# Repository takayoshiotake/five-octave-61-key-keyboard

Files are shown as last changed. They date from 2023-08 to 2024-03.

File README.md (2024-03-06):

# Five Octave

[][cc-by-sa]

A 61-key (5-octave) keyboard. Powered by [Vial](https://get.vial.today/) firmware.

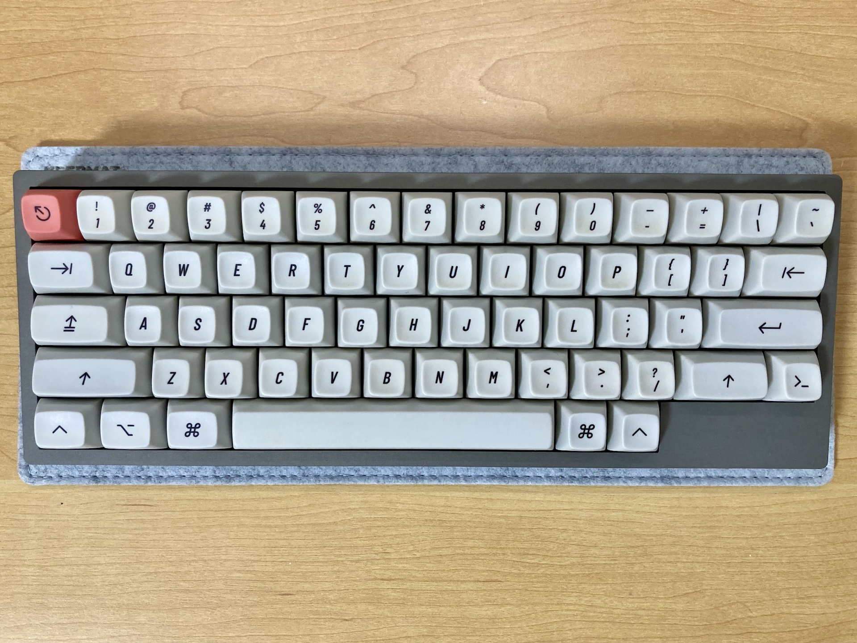
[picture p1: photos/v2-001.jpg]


## Layout

**Layer 0**:

📄 [keyboard-layout.png](layout/keyboard-layout.png) (v0.3.0)

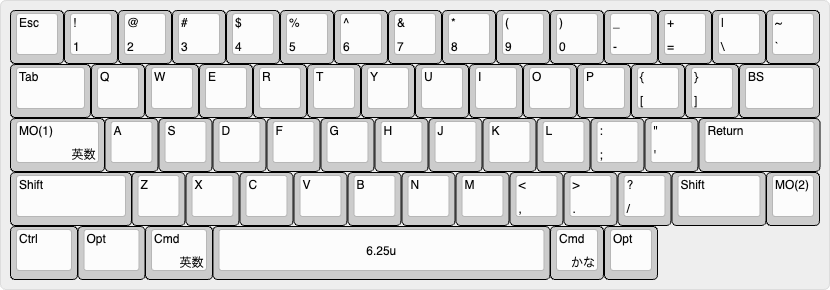
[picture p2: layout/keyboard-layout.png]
keyboard layout


MEMO: When pressed individually and released, it becomes the lower right keys (英数 and かな).

**Layer 1**:

📄 [keyboard-layout-1.png](layout/keyboard-layout-1.png)

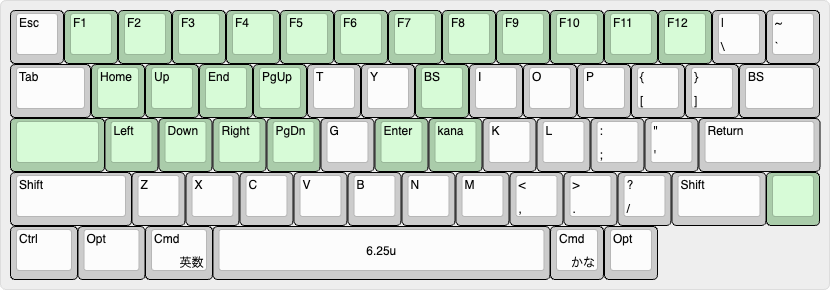
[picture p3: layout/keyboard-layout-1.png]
keyboard layout 1


**Layer 2**:

📄 [keyboard-layout-2.png](layout/keyboard-layout-2.png)

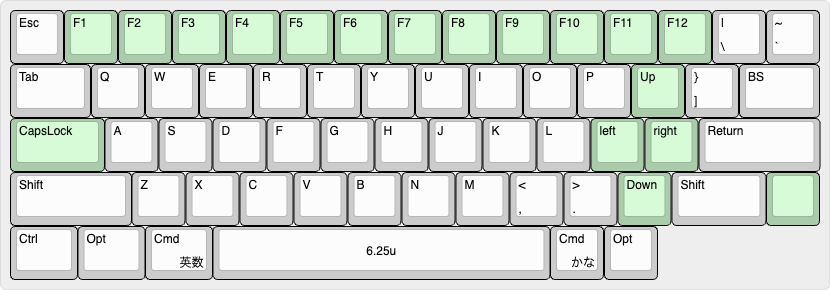
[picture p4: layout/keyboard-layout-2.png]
keyboard layout 2


MEMO: I couldn't figure out how to achieve 'fn' with adafruit_hid, so I'm using Karabiner to remap right_option to 'fn' and using it that way.

**RAW data for Keyboard Layout Editor v0.15:**

📄 [keyboard-layout.rawdata.json](layout/keyboard-layout.rawdata.json)

```json
[{"a":4,"f":3},"Esc","!\n1","@\n2","#\n3","$\n4","%\n5","^\n6","&\n7","*\n8","(\n9",")\n0","_\n-","+\n=","|\n\\","~\n`"],
[{"w":1.5},"Tab","Q","W","E","R","T","Y","U","I","O","P","{\n[","}\n]",{"w":1.5},"BS"],
[{"w":1.75},"MO(1)\n\n\n英数","A","S","D","F","G","H","J","K","L",":\n;","\"\n'",{"w":2.25},"Return"],
[{"w":2.25},"Shift","Z","X","C","V","B","N","M","<\n,",">\n.","?\n/",{"w":1.75},"Shift","MO(2)"],
[{"w":1.25},"Ctrl",{"w":1.25},"Opt",{"w":1.25},"Cmd\n\n\n英数",{"a":7,"w":6.25},"6.25u",{"a":4},"Cmd\n\n\nかな","Opt"]
```

📄 [keyboard-layout-1.rawdata.json](layout/keyboard-layout-1.rawdata.json)

```json
[{"a":4,"f":3},"Esc",{"c":"#aaccaa"},"F1","F2","F3","F4","F5","F6","F7","F8","F9","F10","F11","F12",{"c":"#cccccc"},"|\n\\","~\n`"],
[{"w":1.5},"Tab",{"c":"#aaccaa"},"Home","Up","End","PgUp",{"c":"#cccccc"},"T","Y","BS",{"c":"#cccccc"},"I","O","P","{\n[","}\n]",{"w":1.5},"BS"],
[{"c":"#aaccaa","w":1.75},"","Left","Down","Right","PgDn",{"c":"#cccccc"},"G",{"c":"#aaccaa"},"Enter","kana",{"c":"#cccccc"},"K","L",":\n;","\"\n'",{"w":2.25},"Return"],
[{"w":2.25},"Shift","Z","X","C","V","B","N","M","<\n,",">\n.","?\n/",{"w":1.75},"Shift",{"c":"#aaccaa"},"",{"c":"#cccccc"}],
[{"w":1.25},"Ctrl",{"w":1.25},"Opt",{"w":1.25},"Cmd\n\n\n英数",{"a":7,"w":6.25},"6.25u",{"a":4},"Cmd\n\n\nかな","Opt"]
```

📄 [keyboard-layout-2.rawdata.json](layout/keyboard-layout-2.rawdata.json)

```json
[{"a":4,"f":3},"Esc",{"c":"#aaccaa"},"F1","F2","F3","F4","F5","F6","F7","F8","F9","F10","F11","F12",{"c":"#cccccc"},"|\n\\","~\n`"],
[{"w":1.5},"Tab","Q","W","E","R","T","Y","U","I","O","P",{"c":"#aaccaa"},"Up",{"c":"#cccccc"},"}\n]",{"w":1.5},"BS"],
[{"c":"#aaccaa","w":1.75},"CapsLock",{"c":"#cccccc"},"A","S","D","F","G","H","J","K","L",{"c":"#aaccaa"},"left","right",{"c":"#cccccc","w":2.25},"Return"],
[{"w":2.25},"Shift","Z","X","C","V","B","N","M","<\n,",">\n.",{"c":"#aaccaa"},"Down",{"c":"#cccccc","w":1.75},"Shift",{"c":"#aaccaa"},"",{"c":"#cccccc"}],
[{"w":1.25},"Ctrl",{"w":1.25},"Opt",{"w":1.25},"Cmd\n\n\n英数",{"a":7,"w":6.25},"6.25u",{"a":4},"Cmd\n\n\nかな","Opt"]]
```

- 🔗 [Keyboard Layout Editor](http://www.keyboard-layout-editor.com/)

## BOM

| Material | QTY | Note |
|-|-:|-|
| Five Octave MCU Board | 1 | |
| Five Octave Keys Board | 1 | |
| Five Octave Enclosure | 1 | |
| 0151660169 | 1 | Molex 0.50mm pitch FFC, Type A, 127.00mm, 16 circuits |

- 🔗 [Molex Connector Part Number - 15166-0169 | Molex](https://www.molex.com/en-us/products/part-detail/151660169)

### Five Octave MCU Board

| Material | Symbol | QTY | Note | JLCPCB Part # |
|-|-|-:|-|-|
| 30pF 0402 | C1, C2 | 2 | | [C1570](https://jlcpcb.com/partdetail/1922-0402CG300J500NT/C1570) |
| 1uF 0402 | C3, C4 | 2 | | [C52923](https://jlcpcb.com/partdetail/53938-CL05A105KA5NQNC/C52923) |
| 100nF 0402 | C5-C14 | 10 | | [C307331](https://jlcpcb.com/partdetail/291005-CL05B104KB54PNC/C307331) |
| 10uF 0402 | C15, C16 | 2 | | [C15525](https://jlcpcb.com/partdetail/16204-CL05A106MQ5NUNC/C15525) |
| HRO_TYPE-C-31-M-12 | J1 | 1 | USB Type-C Connector, Korean Hroparts Elec | [C165948](https://jlcpcb.com/partdetail/Korean_HropartsElec-TYPE_C_31_M12/C165948) |
| AFC01-S16FCC-00 | J2 | 1 | FFC Connector 0.50mm pitch 16 circuits, JUSHUO | [C262272](https://jlcpcb.com/partdetail/Jushuo-AFC01_S16FCC00/C262272) |
| WS2812C-2020-V1 | LED1 | 1 | NeoPixel RGB LED 2x2mm, Worldsemi | [C2976072](https://jlcpcb.com/partdetail/Worldsemi-WS2812C_2020V1/C2976072) |
| 10KΩ 0402 | R1, R3 | 2 | | [C25744](https://jlcpcb.com/partdetail/26487-0402WGF1002TCE/C25744) |
| 1KΩ 0402 | R2, R4 | 2 | | [C11702](https://jlcpcb.com/partdetail/12256-0402WGF1001TCE/C11702) |
| 27Ω 0402 | R5, R6 | 2 | | [C352446](https://jlcpcb.com/partdetail/Resi-AECR0402F27R0K9/C352446) |
| 5.1KΩ 0402 | R7, R8 | 2 | | [C25905](https://jlcpcb.com/partdetail/26648-0402WGF5101TCE/C25905) |
| SKRPANE010 | SW1, SW2 | 2 | Tactile Switch, ALPS ALPINE | [C470426](https://jlcpcb.com/partdetail/Alpsalpine-SKRPANE010/C470426) |
| RP2040 | U1 | 1 | MCU, Raspberry Pi | [C2040](https://jlcpcb.com/partdetail/RaspberryPi-RP2040/C2040) |
| W25Q64JVXGIQ | U2 | 1 | 64M-bit Serial Flash, Winbond Electronics | [C2940195](https://jlcpcb.com/partdetail/WinbondElec-W25Q64JVXGIQ/C2940195) |
| AP2112K-3.3TRG1 | U3 | 1 | 3.3V Linear Voltage Regulators | [C51118](https://jlcpcb.com/partdetail/DiodesIncorporated-AP2112K_33TRG1/C51118) |
| X322512MSB4SI | Y1 | 1 | 12MHz 20pF Crystal Resonator, SMD-3225, Yangxing Tech | [C9002](https://jlcpcb.com/partdetail/YangxingTech-X322512MSB4SI/C9002) | 

### Five Octave Keys Board

| Material | Symbol | QTY | Note | JLCPCB Part # |
|-|-|-:|-|-|
| 1N4148WS | D1-D61 | 61 | | [C2128](https://jlcpcb.com/partdetail/2485-1N4148WS/C2128) |
| CPG151101S11-16 | SW1-SW61 | 61 | How Swap Socket, Kailh | [C5156480](https://jlcpcb.com/partdetail/Kailh-CPG151101S1116/C5156480) | 
| AFC01-S16FCC-00 | J1 | 1 | FFC Connector 0.50mm pitch 16 circuits, JUSHUO | [C262272](https://jlcpcb.com/partdetail/Jushuo-AFC01_S16FCC00/C262272) |

- 🔗 [JLCPCB | Assembly Parts Lib](https://jlcpcb.com/parts)

### Five Octave Enclosure

| Material | Symbol | QTY | Note |
|-|-|-:|-|
| Five Octave Enclosure - Case || 1 | (or Enclosure v2) |
| Five Octave Enclosure - Top Frame || 1 | (or Enclosure v2) |
| Screw M2 x 8mm || 4 | Secure Case and Top Frame |
| Screw M2 x 5mm or 4mm || 4 | Secure Case and Five Octave MCU |
| Poron 1.5t 3mm x 120mm || 2 | For gasket mounting |
| Poron 1.5t 3mm x 60mm || 6 | For gasket mounting |
| Poron 1.5t 3mm x 40mm || 2 | For gasket mounting |

## Schematic and PCB

### Five Octave MCU

📄 [Five_Octave_MCU.kicad_sch](electronics/Five_Octave_MCU/Five_Octave_MCU.kicad_sch) (v1.0.0)

📄 [Five_Octave_MCU.kicad_pcb](electronics/Five_Octave_MCU/Five_Octave_MCU.kicad_pcb) (v1.0.0)

📄 [Five_Octave_MCU.svg](electronics/Five_Octave_MCU/Five_Octave_MCU.svg)

schematic svg

### Five Octave Keys

📄 [Five_Octave_Keys.kicad_sch](electronics/Five_Octave_Keys/Five_Octave_Keys.kicad_sch) (v1.0.0)

📄 [Five_Octave_Keys.kicad_pcb](electronics/Five_Octave_Keys/Five_Octave_Keys.kicad_pcb) (v1.0.0)

📄 [Five_Octave_Keys.svg](electronics/Five_Octave_Keys/Five_Octave_Keys.svg)

schematic svg

#### Key-matrix (8x8)

| | C0 | C1 | C2  | C3  | C4 | C5 | C6 | C7 |
|----|---|---|-----|-----|---|---|---|---|
| R0 | Esc | | 1 | 2 | 3 | 4 | 5 | 6 |
| R1 | Tab | | | Q | W | E | R | T |
| R2 | Caps  | Z | X | A | S | D | F | G | 
| R3 | Shift | Ctrl | Opt | Cmd | Space | C | V | B |
| R4 | 7 | 8 | 9 | 0 | - | = | \ | ` |
| R5 | Y | U | I | O | P | [ | ] | BS |
| R6 | H | J | K | L | ; | ' | Return | Fn |
| R7 | N | M | , | . | / | Shift | Cmd | MO(1) | 

## Mechanics

### Five Octave Enclosure

📄 [Five_Octave_Enclosure.FCStd](mechanics/Five_Octave_Enclosure.FCStd) (v1.0.1)

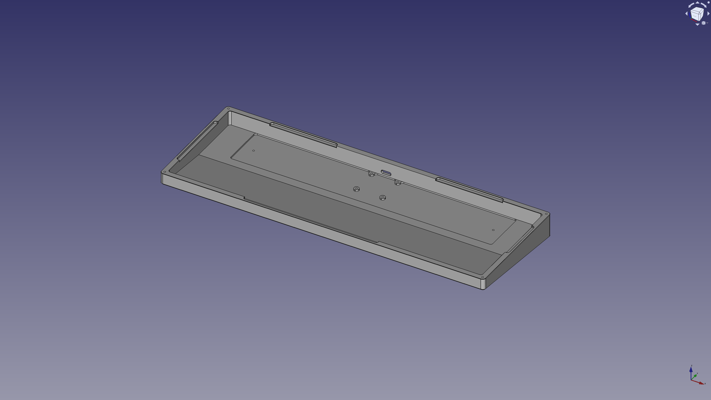
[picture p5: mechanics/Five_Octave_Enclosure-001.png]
enclosure png 001

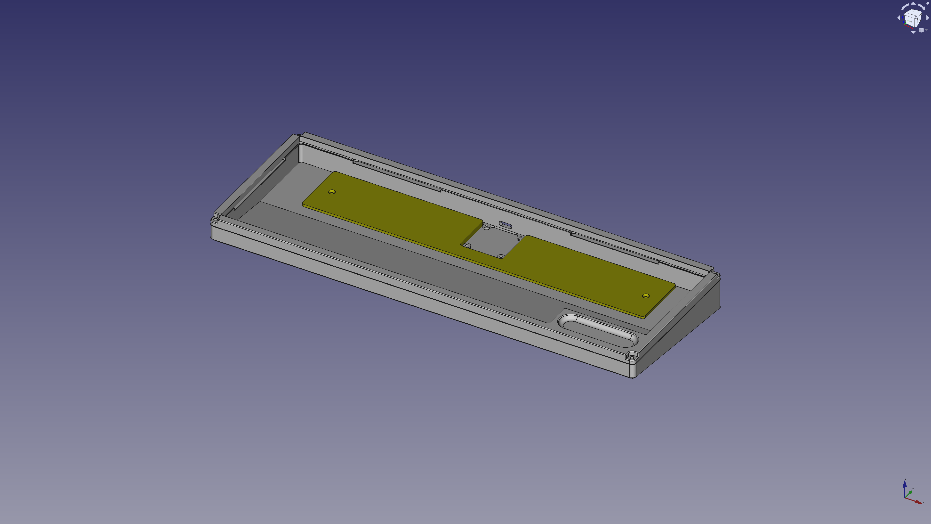
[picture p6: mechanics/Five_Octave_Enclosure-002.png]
enclosure png 002


### Five Octave Enclosure v2

📄 [Five_Octave_Enclosure_v2.FCStd](mechanics/Five_Octave_Enclosure_v2.FCStd) (v2.1.2)

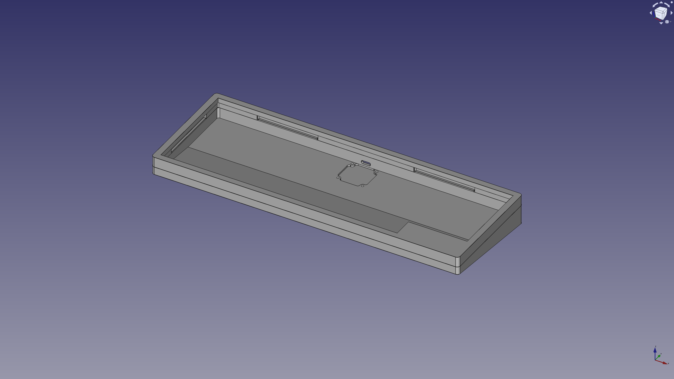
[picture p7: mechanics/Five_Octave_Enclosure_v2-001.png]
enclosure v2 png 001

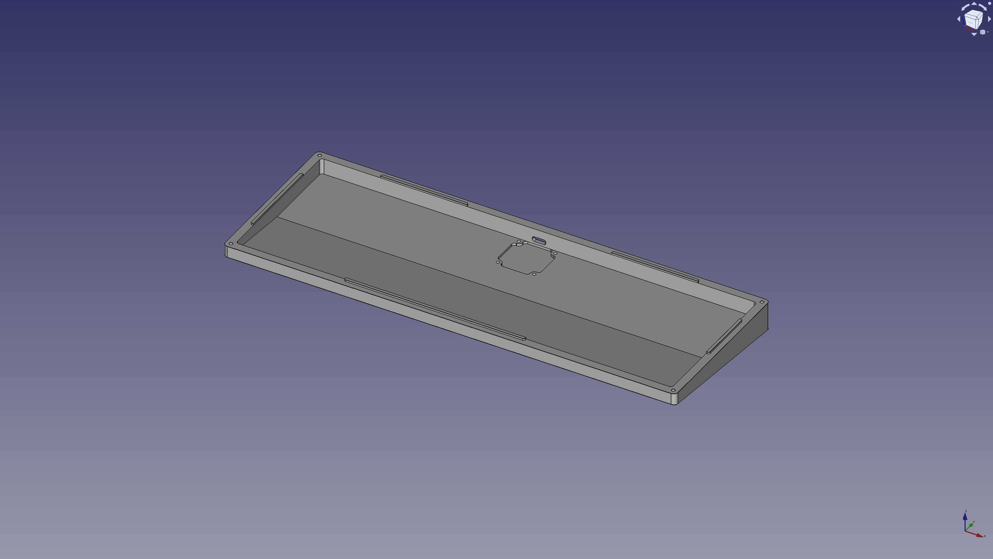
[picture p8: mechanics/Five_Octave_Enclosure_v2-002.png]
enclosure v2 png 002


### Plate

📄 [Five_Octave_Plate.kicad_pcb](electronics/Five_Octave_Plate/Five_Octave_Plate.kicad_pcb) (v1.0.0)

## Firmware

You can use Vial or CircuitPython.

### Vial

- Built UF2
    - 📄 [takayoshiotake_five_octave_vial_20240103.uf2](vial-bin/takayoshiotake_five_octave_vial_20240103.uf2)
- Code
    -  🔗 <https://github.com/vial-kb/vial-qmk/tree/vial/keyboards/takayoshiotake/five_octave>
    -  🔗 <https://github.com/vial-kb/vial-qmk/tree/49f5eec0d46f3524850885ffae9dee2982312e50>

See [vial-porting](vial-porting) for more details.

### CircuitPython

Software for the Five Octave runs on CircuitPython.
Its CircuitPython is the same as the one for Octave (<https://github.com/takayoshiotake/octave-12-key-macropad>).

- Built UF2
    - 🔗 <https://adafruit-circuit-python.s3.amazonaws.com/index.html?prefix=bin/takayoshiotake_octave_rp2040/>
    - 📄 [adafruit-circuitpython-takayoshiotake_octave_rp2040-en_US-8.2.6.uf2](circuitpython-bin/adafruit-circuitpython-takayoshiotake_octave_rp2040-en_US-8.2.6.uf2)
- Code
    - 🔗 [adafruit/circuitpython](https://github.com/adafruit/circuitpython)
        - 🔗 <https://github.com/adafruit/circuitpython/tree/main/ports/raspberrypi/boards/takayoshiotake_octave_rp2040>

See [circuitpython-app/README.md](software/README.md) for application software.

## Gallery

Keycap: Drop + biip MT3 Extended 2048

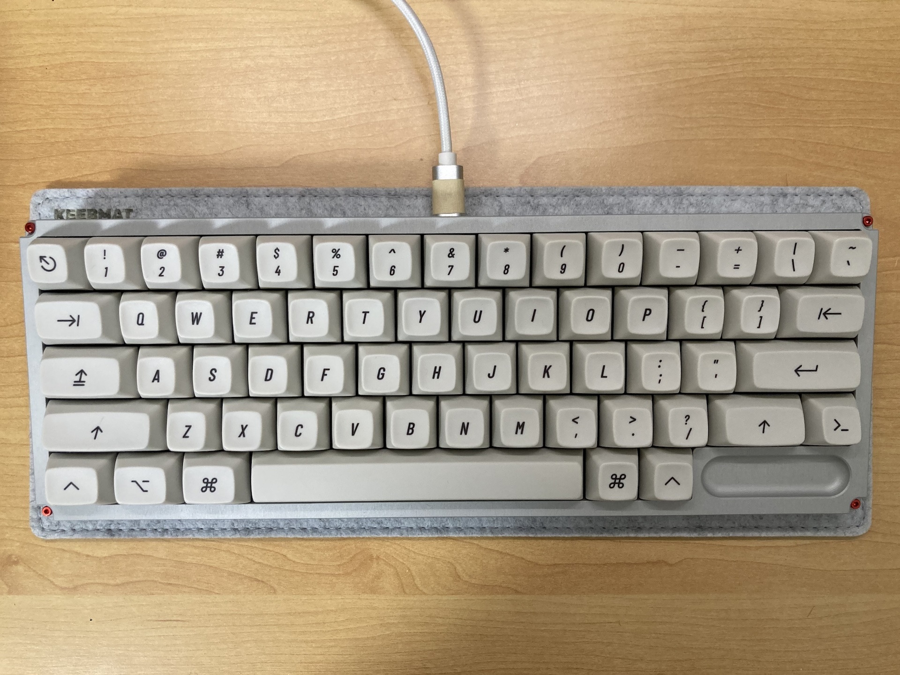
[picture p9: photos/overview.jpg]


MEMO: Alminum 6061 CNC + Bead blasting 120 mesh + Anodizing natural matte by JLCPCB (Five Octave Enclosure v1.0.0)

### Photos with Enclosure v2

Keycap: Drop + biip MT3 Extended 2048


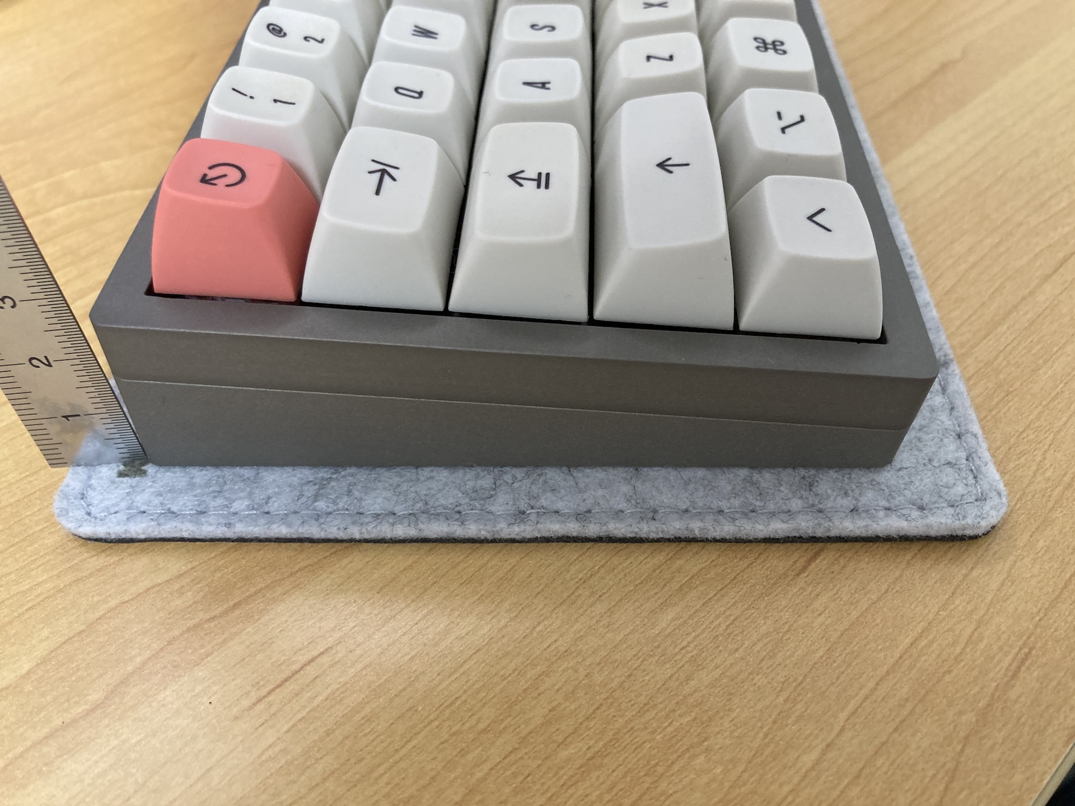
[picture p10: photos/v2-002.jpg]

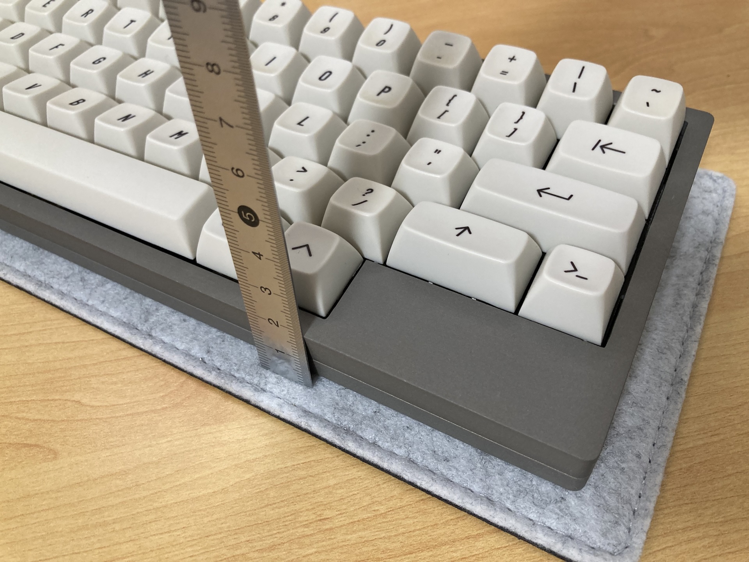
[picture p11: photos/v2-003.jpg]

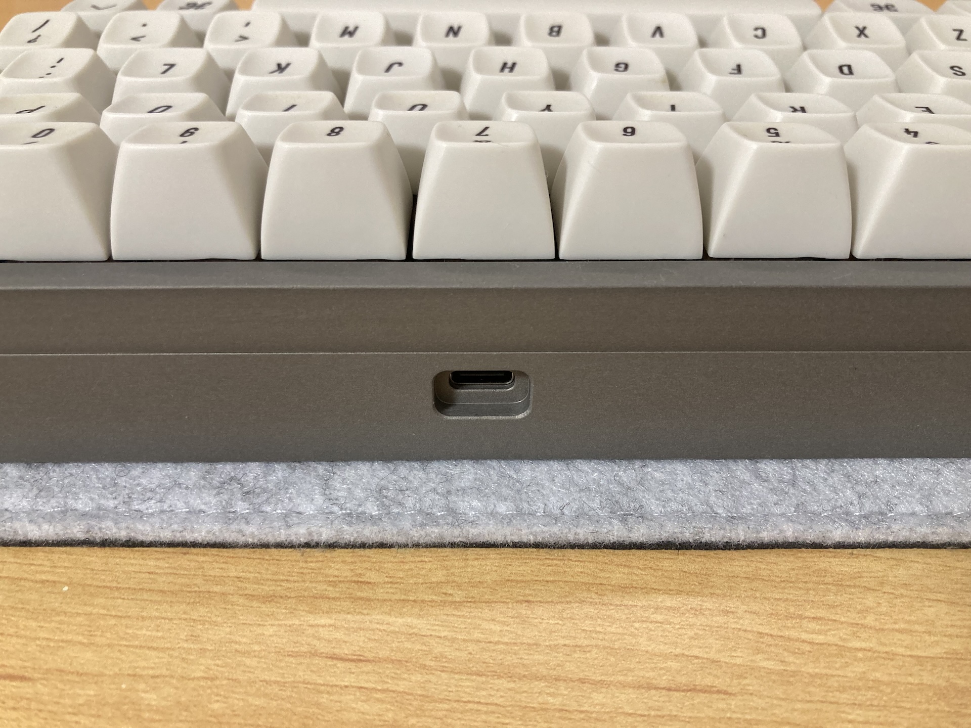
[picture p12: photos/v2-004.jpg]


MEMO: Alminum 6061 CNC + Bead blasting 150 mesh + Hardcoat anodizing natural matte by JLCPCB (Five Octave Enclosure v2.1.1)

## License

This work is licensed under a
[Creative Commons Attribution-ShareAlike 4.0 International License][cc-by-sa].

[][cc-by-sa]

[cc-by-sa]: http://creativecommons.org/licenses/by-sa/4.0/
[cc-by-sa-image]: https://licensebuttons.net/l/by-sa/4.0/88x31.png
[cc-by-sa-shield]: https://img.shields.io/badge/license-CC%20BY--SA%204.0-lightgrey.svg

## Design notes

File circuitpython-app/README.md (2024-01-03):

# CircuitPython app

## Setup

1. Install CircuitPython 8.x.x
    1. Connect Octave via USB
    2. Reboot Octave by holding down BOOT and pressing RESET
    3. Copy (drag & drop) uf2 to RPI-RP2
        - 📄 [adafruit-circuitpython-takayoshiotake_octave_rp2040-en_US-8.2.6.uf2](../circuitpython-bin/adafruit-circuitpython-takayoshiotake_octave_rp2040-en_US-8.2.6.uf2)
        - 🔗 <https://circuitpython.org/board/takayoshiotake_octave_rp2040/>

2. Renaming CIRCUITPY to OCTAVE_CP

    - 🔗 <https://learn.adafruit.com/welcome-to-circuitpython/renaming-circuitpy>

## Install packages

```shell-session
% poetry install
% poetry shell
(.venv) % circup --path /Volumes/OCTAVE_CP install -r requirements.txt
```

Alternatively:

```shell-session
% cp -r lib /Volumes/OCTAVE_CP/
```

## Upload

```shell-session
% cp boot.py code.py /Volumes/OCTAVE_CP/
% cp -r octave_pcb /Volumes/OCTAVE_CP/
```

MEMO: After uploading boot.py, you will need to hold down SW1 during boot to mount it as a USB drive.

## Note

🔗 <https://learn.adafruit.com/circuitpython-essentials/circuitpython-resetting>

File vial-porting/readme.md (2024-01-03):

# Five Octave

Five Octave

Vial firmware for the Five Octave 60% keyboard. You can find other information including hardware design in the [GitHub repository](https://github.com/takayoshiotake/five-octave-61-key-keyboard).

Keyboard Maintainer: [takayoshiotake](https://github.com/takayoshiotake)

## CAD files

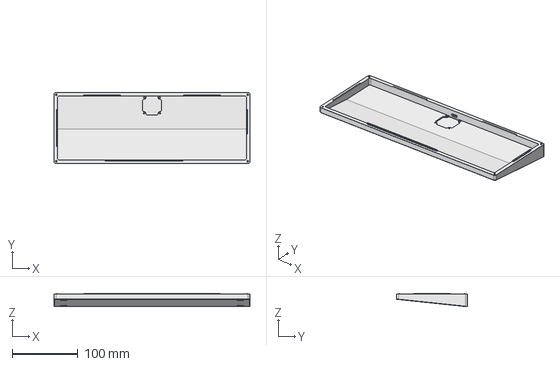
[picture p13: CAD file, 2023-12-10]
mechanics/Five_Octave_Enclosure_v2.FCStd
298.9 x 108.4 x 20.5 mm

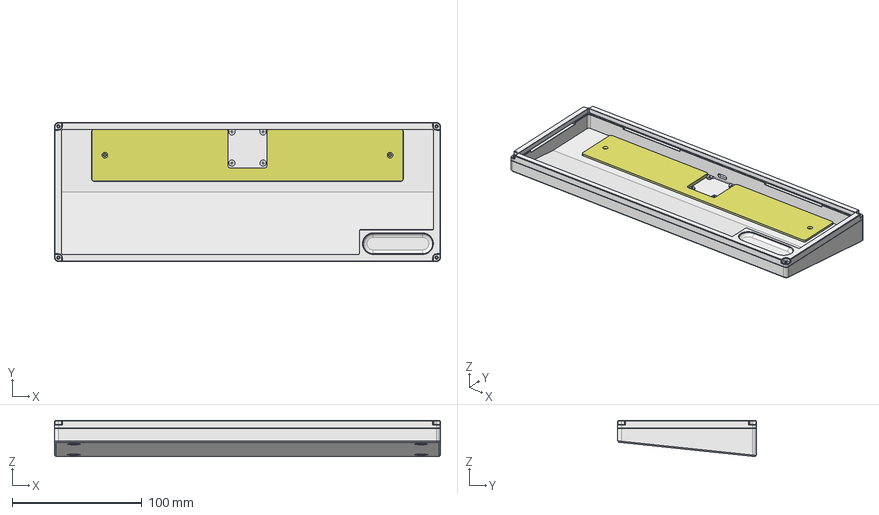
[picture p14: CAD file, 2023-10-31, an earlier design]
mechanics/Five_Octave_Enclosure.FCStd
297.8 x 107.3 x 27.9 mm
Case
Top Frame
Weight

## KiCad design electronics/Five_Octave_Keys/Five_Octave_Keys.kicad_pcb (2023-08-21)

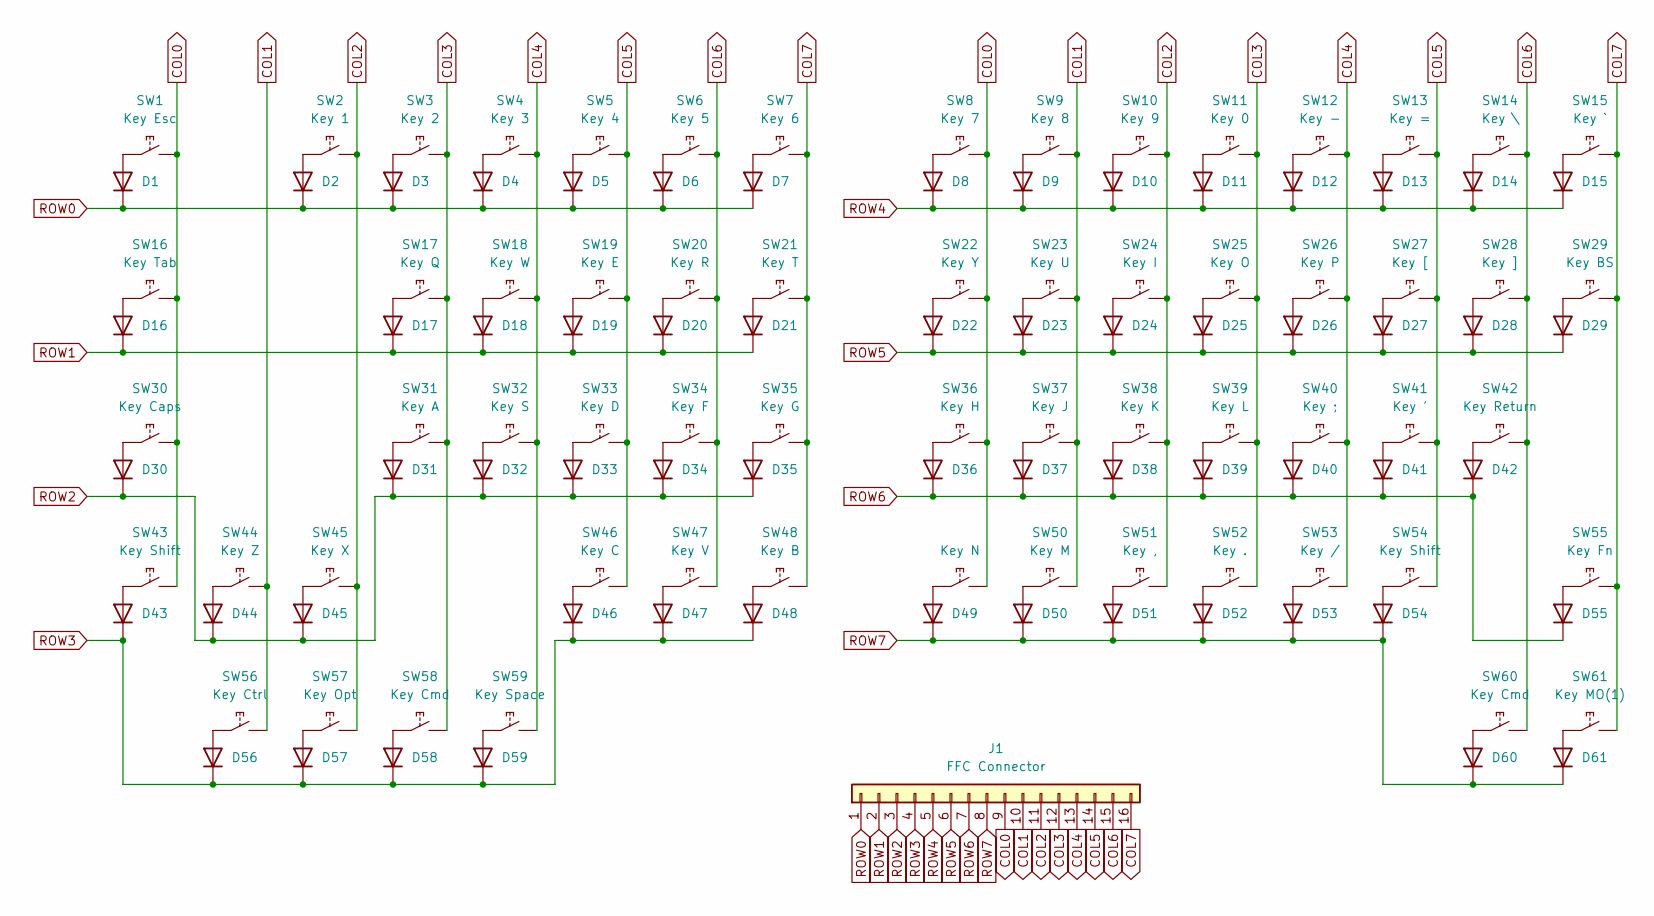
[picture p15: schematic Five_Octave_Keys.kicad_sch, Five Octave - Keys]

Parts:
D1, D2, D3, D4, D5, D6, D7, D8, D9, D10, D11, D12, D13, D14, D15, D16, D17, D18, D19, D20, D21, D22, D23, D24, D25, D26, D27, D28, D29, D30, D31, D32, D33, D34, D35, D36, D37, D38, D39, D40, D41, D42, D43, D44, D45, D46, D47, D48, D49, D50, D51, D52, D53, D54, D55, D56, D57, D58, D59, D60, D61: 1N4148WS; D_SOD-323F; LCSC C2128
J1: FFC Connector; JUSHUO_AFC01-S16FCC-00; LCSC C262272
SW1: Key Esc; Hot_Swap_Socket_CPG151101S11; LCSC C5156480
SW2: Key 1; Hot_Swap_Socket_CPG151101S11; LCSC C5156480
SW3: Key 2; Hot_Swap_Socket_CPG151101S11; LCSC C5156480
SW4: Key 3; Hot_Swap_Socket_CPG151101S11; LCSC C5156480
SW5: Key 4; Hot_Swap_Socket_CPG151101S11; LCSC C5156480
SW6: Key 5; Hot_Swap_Socket_CPG151101S11; LCSC C5156480
SW7: Key 6; Hot_Swap_Socket_CPG151101S11; LCSC C5156480
SW8: Key 7; Hot_Swap_Socket_CPG151101S11; LCSC C5156480
SW9: Key 8; Hot_Swap_Socket_CPG151101S11; LCSC C5156480
SW10: Key 9; Hot_Swap_Socket_CPG151101S11; LCSC C5156480
SW11: Key 0; Hot_Swap_Socket_CPG151101S11; LCSC C5156480
SW12: Key -; Hot_Swap_Socket_CPG151101S11; LCSC C5156480
SW13: Key =; Hot_Swap_Socket_CPG151101S11; LCSC C5156480
SW14: Key \; Hot_Swap_Socket_CPG151101S11; LCSC C5156480
SW15: Key `; Hot_Swap_Socket_CPG151101S11; LCSC C5156480
SW16: Key Tab; Hot_Swap_Socket_CPG151101S11; LCSC C5156480
SW17: Key Q; Hot_Swap_Socket_CPG151101S11; LCSC C5156480
SW18: Key W; Hot_Swap_Socket_CPG151101S11; LCSC C5156480
SW19: Key E; Hot_Swap_Socket_CPG151101S11; LCSC C5156480
SW20: Key R; Hot_Swap_Socket_CPG151101S11; LCSC C5156480
SW21: Key T; Hot_Swap_Socket_CPG151101S11; LCSC C5156480
SW22: Key Y; Hot_Swap_Socket_CPG151101S11; LCSC C5156480
SW23: Key U; Hot_Swap_Socket_CPG151101S11; LCSC C5156480
SW24: Key I; Hot_Swap_Socket_CPG151101S11; LCSC C5156480
SW25: Key O; Hot_Swap_Socket_CPG151101S11; LCSC C5156480
SW26: Key P; Hot_Swap_Socket_CPG151101S11; LCSC C5156480
SW27: Key [; Hot_Swap_Socket_CPG151101S11; LCSC C5156480
SW28: Key ]; Hot_Swap_Socket_CPG151101S11; LCSC C5156480
SW29: Key BS; Hot_Swap_Socket_CPG151101S11; LCSC C5156480
SW30: Key Caps; Hot_Swap_Socket_CPG151101S11; LCSC C5156480
SW31: Key A; Hot_Swap_Socket_CPG151101S11; LCSC C5156480
SW32: Key S; Hot_Swap_Socket_CPG151101S11; LCSC C5156480
SW33: Key D; Hot_Swap_Socket_CPG151101S11; LCSC C5156480
SW34: Key F; Hot_Swap_Socket_CPG151101S11; LCSC C5156480
SW35: Key G; Hot_Swap_Socket_CPG151101S11; LCSC C5156480
SW36: Key H; Hot_Swap_Socket_CPG151101S11; LCSC C5156480
SW37: Key J; Hot_Swap_Socket_CPG151101S11; LCSC C5156480
SW38: Key K; Hot_Swap_Socket_CPG151101S11; LCSC C5156480
SW39: Key L; Hot_Swap_Socket_CPG151101S11; LCSC C5156480
SW40: Key ;; Hot_Swap_Socket_CPG151101S11; LCSC C5156480
SW41: Key '; Hot_Swap_Socket_CPG151101S11; LCSC C5156480
SW42: Key Return; Hot_Swap_Socket_CPG151101S11; LCSC C5156480
SW43, SW54: Key Shift; Hot_Swap_Socket_CPG151101S11; LCSC C5156480
SW44: Key Z; Hot_Swap_Socket_CPG151101S11; LCSC C5156480
SW45: Key X; Hot_Swap_Socket_CPG151101S11; LCSC C5156480
SW46: Key C; Hot_Swap_Socket_CPG151101S11; LCSC C5156480
SW47: Key V; Hot_Swap_Socket_CPG151101S11; LCSC C5156480
SW48: Key B; Hot_Swap_Socket_CPG151101S11; LCSC C5156480
SW49: Key N; Hot_Swap_Socket_CPG151101S11; LCSC C5156480
SW50: Key M; Hot_Swap_Socket_CPG151101S11; LCSC C5156480
SW51: Key ,; Hot_Swap_Socket_CPG151101S11; LCSC C5156480
SW52: Key .; Hot_Swap_Socket_CPG151101S11; LCSC C5156480
SW53: Key /; Hot_Swap_Socket_CPG151101S11; LCSC C5156480
SW55: Key Fn; Hot_Swap_Socket_CPG151101S11; LCSC C5156480
SW56: Key Ctrl; Hot_Swap_Socket_CPG151101S11; LCSC C5156480
SW57: Key Opt; Hot_Swap_Socket_CPG151101S11; LCSC C5156480
SW58, SW60: Key Cmd; Hot_Swap_Socket_CPG151101S11; LCSC C5156480
SW59: Key Space; Hot_Swap_Socket_CPG151101S11; LCSC C5156480
SW61: Key MO(1); Hot_Swap_Socket_CPG151101S11; LCSC C5156480

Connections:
COL0: J1.9, SW1.2, SW8.2, SW16.2, SW22.2, SW30.2, SW36.2, SW43.2, SW49.2
COL1: J1.10, SW9.2, SW23.2, SW37.2, SW44.2, SW50.2, SW56.2
COL2: J1.11, SW2.2, SW10.2, SW24.2, SW38.2, SW45.2, SW51.2, SW57.2
COL3: J1.12, SW3.2, SW11.2, SW17.2, SW25.2, SW31.2, SW39.2, SW52.2, SW58.2
COL4: J1.13, SW4.2, SW12.2, SW18.2, SW26.2, SW32.2, SW40.2, SW53.2, SW59.2
COL5: J1.14, SW5.2, SW13.2, SW19.2, SW27.2, SW33.2, SW41.2, SW46.2, SW54.2
COL6: J1.15, SW6.2, SW14.2, SW20.2, SW28.2, SW34.2, SW42.2, SW47.2, SW60.2
COL7: J1.16, SW7.2, SW15.2, SW21.2, SW29.2, SW35.2, SW48.2, SW55.2, SW61.2
unnamed: D1.2 (A), SW1.1
unnamed: D2.2 (A), SW2.1
unnamed: D3.2 (A), SW3.1
unnamed: D4.2 (A), SW4.1
unnamed: D5.2 (A), SW5.1
unnamed: D6.2 (A), SW6.1
unnamed: D7.2 (A), SW7.1
unnamed: D8.2 (A), SW8.1
unnamed: D9.2 (A), SW9.1
unnamed: D10.2 (A), SW10.1
unnamed: D11.2 (A), SW11.1
unnamed: D12.2 (A), SW12.1
unnamed: D13.2 (A), SW13.1
unnamed: D14.2 (A), SW14.1
unnamed: D15.2 (A), SW15.1
unnamed: D16.2 (A), SW16.1
unnamed: D17.2 (A), SW17.1
unnamed: D18.2 (A), SW18.1
unnamed: D19.2 (A), SW19.1
unnamed: D20.2 (A), SW20.1
unnamed: D21.2 (A), SW21.1
unnamed: D22.2 (A), SW22.1
unnamed: D23.2 (A), SW23.1
unnamed: D24.2 (A), SW24.1
unnamed: D25.2 (A), SW25.1
unnamed: D26.2 (A), SW26.1
unnamed: D27.2 (A), SW27.1
unnamed: D28.2 (A), SW28.1
unnamed: D29.2 (A), SW29.1
unnamed: D30.2 (A), SW30.1
unnamed: D31.2 (A), SW31.1
unnamed: D32.2 (A), SW32.1
unnamed: D33.2 (A), SW33.1
unnamed: D34.2 (A), SW34.1
unnamed: D35.2 (A), SW35.1
unnamed: D36.2 (A), SW36.1
unnamed: D37.2 (A), SW37.1
unnamed: D38.2 (A), SW38.1
unnamed: D39.2 (A), SW39.1
unnamed: D40.2 (A), SW40.1
unnamed: D41.2 (A), SW41.1
unnamed: D42.2 (A), SW42.1
unnamed: D43.2 (A), SW43.1
unnamed: D44.2 (A), SW44.1
unnamed: D45.2 (A), SW45.1
unnamed: D46.2 (A), SW46.1
unnamed: D47.2 (A), SW47.1
unnamed: D48.2 (A), SW48.1
unnamed: D49.2 (A), SW49.1
unnamed: D50.2 (A), SW50.1
unnamed: D51.2 (A), SW51.1
unnamed: D52.2 (A), SW52.1
unnamed: D53.2 (A), SW53.1
unnamed: D54.2 (A), SW54.1
unnamed: D55.2 (A), SW55.1
unnamed: D56.2 (A), SW56.1
unnamed: D57.2 (A), SW57.1
unnamed: D58.2 (A), SW58.1
unnamed: D59.2 (A), SW59.1
unnamed: D60.2 (A), SW60.1
unnamed: D61.2 (A), SW61.1
ROW0: D1.1 (K), D2.1 (K), D3.1 (K), D4.1 (K), D5.1 (K), D6.1 (K), D7.1 (K), J1.1
ROW1: D16.1 (K), D17.1 (K), D18.1 (K), D19.1 (K), D20.1 (K), D21.1 (K), J1.2
ROW2: D30.1 (K), D31.1 (K), D32.1 (K), D33.1 (K), D34.1 (K), D35.1 (K), D44.1 (K), D45.1 (K), J1.3
ROW3: D43.1 (K), D46.1 (K), D47.1 (K), D48.1 (K), D56.1 (K), D57.1 (K), D58.1 (K), D59.1 (K), J1.4
ROW4: D8.1 (K), D9.1 (K), D10.1 (K), D11.1 (K), D12.1 (K), D13.1 (K), D14.1 (K), D15.1 (K), J1.5
ROW5: D22.1 (K), D23.1 (K), D24.1 (K), D25.1 (K), D26.1 (K), D27.1 (K), D28.1 (K), D29.1 (K), J1.6
ROW6: D36.1 (K), D37.1 (K), D38.1 (K), D39.1 (K), D40.1 (K), D41.1 (K), D42.1 (K), D55.1 (K), J1.7
ROW7: D49.1 (K), D50.1 (K), D51.1 (K), D52.1 (K), D53.1 (K), D54.1 (K), D60.1 (K), D61.1 (K), J1.8

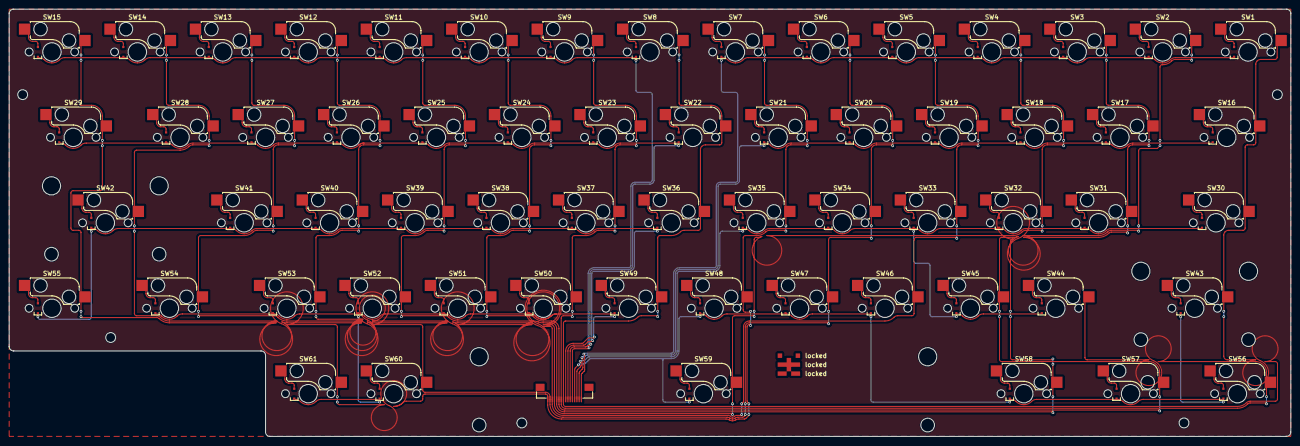
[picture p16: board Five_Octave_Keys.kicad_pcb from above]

Board: 2 copper layers, 285.8 x 95.2 mm, 123 parts (0 on the bottom side), 77 nets.

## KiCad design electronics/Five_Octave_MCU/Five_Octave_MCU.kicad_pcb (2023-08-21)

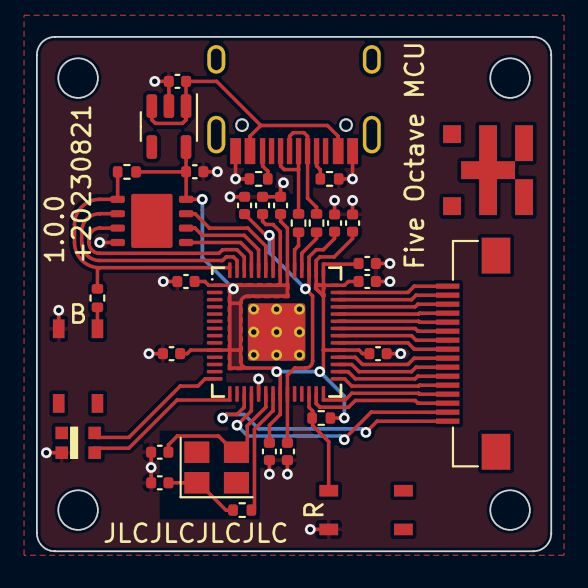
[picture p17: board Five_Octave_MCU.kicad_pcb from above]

Board: 2 copper layers, 28.6 x 28.6 mm, 33 parts (0 on the bottom side), 39 nets.

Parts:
C1, C2: 30pF; C_0402_1005Metric
C3, C4: 1uF; C_0402_1005Metric
C5, C6, C7, C8, C9, C10, C11, C12, C13, C14: 0.1uF; C_0402_1005Metric
C15, C16: 10uF; C_0402_1005Metric
J1: HRO_TYPE-C-31-M-12
J2: FFC Connector; JUSHUO_AFC01-S16FCC-00
LED1: WS2812C-2020-V1; WS2812C-2020
R1, R3: 10K; R_0402_1005Metric
R2, R4: 1K; R_0402_1005Metric
R5, R6: 27; R_0402_1005Metric
R7, R8: 5.1K; R_0402_1005Metric
SW1, SW2: Alps_Alpine_SKRP; Tactile_Switch_SKRP_Series
U1: Raspberry_Pi_RP2040; RP2040_QFN-56
U2: W25Q64JVXGIQ; XSON-8-EP_4x4mm
U3: AP2112K-3.3; SOT-23-5
Y1: 12MHz; Crystal_SMD_3225-4Pin_3.2x2.5mm

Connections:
+1V1: C4.1, C13.1, C14.1, U1.23 (DVDD), U1.45 (VREG_VOUT), U1.50 (DVDD)
+3V3: C3.1, C5.1, C6.1, C7.1, C8.1, C9.1, C10.1, C11.1, C12.1, C16.1, R1.1, R3.1, U1.1 (IOVDD), U1.10 (IOVDD), U1.22 (IOVDD), U1.33 (IOVDD), U1.42 (IOVDD), U1.43 (ADC_AVDD), U1.44 (VREG_VIN), U1.48 (USB_VDD), U1.49 (IOVDD), U2.8 (VCC), U3.5 (VOUT)
+5V: C15.1, J1.A4/B9 (VBUS), J1.A9/B4 (VBUS), U3.1 (VIN), U3.3 (EN)
COL0: J2.8, U1.32 (GPIO21)
COL1: J2.7, U1.31 (GPIO20)
COL2: J2.6, U1.30 (GPIO19)
COL3: J2.5, U1.29 (GPIO18)
COL4: J2.4, U1.28 (GPIO17)
COL5: J2.3, U1.27 (GPIO16)
COL6: J2.2, U1.18 (GPIO15)
COL7: J2.1, U1.17 (GPIO14)
D+: R5.1, U1.47 (USB_DP)
D-: R6.1, U1.46 (USB_DM)
GND: C1.2, C2.2, C3.2, C4.2, C5.2, C6.2, C7.2, C8.2, C9.2, C10.2, C11.2, C12.2, C13.2, C14.2, C15.2, C16.2, J1.A1/B12 (GND), J1.A12/B1 (GND), LED1.3 (VSS), R7.2, R8.2, SW1.3, SW2.3, U1.19 (TESTEN), U1.57 (GND), U2.4 (GND), U3.2 (GND)
NEOPIX: LED1.4 (DIN), U1.15 (GPIO12)
NEOPIX_POWER: LED1.1 (VDD), U1.14 (GPIO11)
unnamed: C2.1, R2.2, Y1.1
unnamed: J1.A5 (CC1), R8.1
unnamed: J1.B5 (CC2), R7.1
unnamed: J1.A6 (D+), J1.B6 (D+), R5.2
unnamed: J1.A7 (D-), J1.B7 (D-), R6.2
unnamed: R4.2, SW2.1
unnamed: U1.52 (QSPI_SCLK), U2.6 (CLK)
unnamed: U1.53 (QSPI_SD0), U2.5 (DI(IO0))
unnamed: U1.55 (QSPI_SD1), U2.2 (DO(IO1))
unnamed: U1.54 (QSPI_SD2), U2.3 (IO2)
unnamed: U1.51 (QSPI_SD3), U2.7 (IO3)
unnamed: R1.2, SW1.1, U1.26 (RUN)
unnamed: C1.1, U1.20 (XIN), Y1.3
unnamed: R2.1, U1.21 (XOUT)
QSPI_SS_N: R3.2, R4.1, U1.56 (QSPI_SS_N), U2.1 (~CS)
ROW0: J2.16, U1.41 (GPIO29/ADC3)
ROW1: J2.15, U1.40 (GPIO28/ADC2)
ROW2: J2.14, U1.39 (GPIO27/ADC1)
ROW3: J2.13, U1.38 (GPIO26/ADC0)
ROW4: J2.12, U1.37 (GPIO25)
ROW5: J2.11, U1.36 (GPIO24)
ROW6: J2.10, U1.35 (GPIO23)
ROW7: J2.9, U1.34 (GPIO22)

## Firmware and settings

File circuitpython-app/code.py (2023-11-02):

import collections
import time

import board
import digitalio
import usb_hid
from adafruit_hid.consumer_control import ConsumerControl
from adafruit_hid.consumer_control_code import ConsumerControlCode
from adafruit_hid.keyboard import Keyboard
from adafruit_hid.keyboard_layout_us import KeyboardLayoutUS
from adafruit_hid.keycode import Keycode
from adafruit_hid.mouse import Mouse

from octave_pcb.key_event import KeyEvent, KeyEventPlanner
from octave_pcb.key_matrix import KeyMatrix


class CodeType:
  KEYBOARD = 0
  MOUSE_MOVE = 1
  MOUSE_BUTTON = 2
  CONSUMER_CONTROL = 3


class KeycodeJp:
  JAPANESE_HENKAN = 0x8A  # International4
  JAPANESE_MUHENKAN = 0x8B  # International5
  JAPANESE_KANA = 0x90  # LANG1
  JAPANESE_EISUU = 0x91  # LANG2


class KeycodeLayer:
  MO1 = 0xFF01
  MO2 = 0xFF02


def is_code_mo(code):
  return True if code == KeycodeLayer.MO1 or code == KeycodeLayer.MO2 else False


ComplexModifierAssignment = collections.namedtuple('ComplexModifierAssignment', ['modifier', 'code_for_standalone'])
"""
1) If you release the key before it becomes a long press, send the standalone code.
2) When a key becomes a long press, or just before another KeyAssignment becomes press,
    the modifier becomes press.
"""

KeyAssignment = collections.namedtuple('KeyAssignment', ['type', 'code'])
LambdaAssignment = collections.namedtuple('LambdaAssignment', ['on_press', 'on_release'])


SCAN_KEY_MATRIX_INTERVAL = 0.02


KEY_MAP_LAYERS = [
    [
        # ROW0
        KeyAssignment(CodeType.KEYBOARD, Keycode.ESCAPE),
        None,
        KeyAssignment(CodeType.KEYBOARD, Keycode.ONE),
        KeyAssignment(CodeType.KEYBOARD, Keycode.TWO),
        KeyAssignment(CodeType.KEYBOARD, Keycode.THREE),
        KeyAssignment(CodeType.KEYBOARD, Keycode.FOUR),
        KeyAssignment(CodeType.KEYBOARD, Keycode.FIVE),
        KeyAssignment(CodeType.KEYBOARD, Keycode.SIX),
        # ROW1
        KeyAssignment(CodeType.KEYBOARD, Keycode.TAB),
        None,
        None,
        KeyAssignment(CodeType.KEYBOARD, Keycode.Q),
        KeyAssignment(CodeType.KEYBOARD, Keycode.W),
        KeyAssignment(CodeType.KEYBOARD, Keycode.E),
        KeyAssignment(CodeType.KEYBOARD, Keycode.R),
        KeyAssignment(CodeType.KEYBOARD, Keycode.T),
        # ROW2
        ComplexModifierAssignment(KeycodeLayer.MO1, KeycodeJp.JAPANESE_EISUU),  # CAPS_LOCK
        KeyAssignment(CodeType.KEYBOARD, Keycode.Z),
        KeyAssignment(CodeType.KEYBOARD, Keycode.X),
        KeyAssignment(CodeType.KEYBOARD, Keycode.A),
        KeyAssignment(CodeType.KEYBOARD, Keycode.S),
        KeyAssignment(CodeType.KEYBOARD, Keycode.D),
        KeyAssignment(CodeType.KEYBOARD, Keycode.F),
        KeyAssignment(CodeType.KEYBOARD, Keycode.G),
        # ROW3
        KeyAssignment(CodeType.KEYBOARD, Keycode.LEFT_SHIFT),
        KeyAssignment(CodeType.KEYBOARD, Keycode.LEFT_CONTROL),
        KeyAssignment(CodeType.KEYBOARD, Keycode.LEFT_ALT),  # left_option
        ComplexModifierAssignment(Keycode.LEFT_GUI, KeycodeJp.JAPANESE_EISUU),  # left_command
        KeyAssignment(CodeType.KEYBOARD, Keycode.SPACE),
        KeyAssignment(CodeType.KEYBOARD, Keycode.C),
        KeyAssignment(CodeType.KEYBOARD, Keycode.V),
        KeyAssignment(CodeType.KEYBOARD, Keycode.B),
        # ROW4
        KeyAssignment(CodeType.KEYBOARD, Keycode.SEVEN),
        KeyAssignment(CodeType.KEYBOARD, Keycode.EIGHT),
        KeyAssignment(CodeType.KEYBOARD, Keycode.NINE),
        KeyAssignment(CodeType.KEYBOARD, Keycode.ZERO),
        KeyAssignment(CodeType.KEYBOARD, Keycode.MINUS),
        KeyAssignment(CodeType.KEYBOARD, Keycode.EQUALS),
        KeyAssignment(CodeType.KEYBOARD, Keycode.BACKSLASH),
        KeyAssignment(CodeType.KEYBOARD, Keycode.GRAVE_ACCENT),
        # ROW5
        KeyAssignment(CodeType.KEYBOARD, Keycode.Y),
        KeyAssignment(CodeType.KEYBOARD, Keycode.U),
        KeyAssignment(CodeType.KEYBOARD, Keycode.I),
        KeyAssignment(CodeType.KEYBOARD, Keycode.O),
        KeyAssignment(CodeType.KEYBOARD, Keycode.P),
        KeyAssignment(CodeType.KEYBOARD, Keycode.LEFT_BRACKET),
        KeyAssignment(CodeType.KEYBOARD, Keycode.RIGHT_BRACKET),
        KeyAssignment(CodeType.KEYBOARD, Keycode.BACKSPACE),
        # ROW6
        KeyAssignment(CodeType.KEYBOARD, Keycode.H),
        KeyAssignment(CodeType.KEYBOARD, Keycode.J),
        KeyAssignment(CodeType.KEYBOARD, Keycode.K),
        KeyAssignment(CodeType.KEYBOARD, Keycode.L),
        KeyAssignment(CodeType.KEYBOARD, Keycode.SEMICOLON),
        KeyAssignment(CodeType.KEYBOARD, Keycode.QUOTE),
        KeyAssignment(CodeType.KEYBOARD, Keycode.RETURN),
        KeyAssignment(CodeType.KEYBOARD, KeycodeLayer.MO2),
        # ROW7
        KeyAssignment(CodeType.KEYBOARD, Keycode.N),
        KeyAssignment(CodeType.KEYBOARD, Keycode.M),
        KeyAssignment(CodeType.KEYBOARD, Keycode.COMMA),
        KeyAssignment(CodeType.KEYBOARD, Keycode.PERIOD),
        KeyAssignment(CodeType.KEYBOARD, Keycode.FORWARD_SLASH),
        KeyAssignment(CodeType.KEYBOARD, Keycode.RIGHT_SHIFT),
        ComplexModifierAssignment(Keycode.RIGHT_GUI, KeycodeJp.JAPANESE_KANA),  # right_command
        KeyAssignment(CodeType.KEYBOARD, Keycode.RIGHT_ALT),  # right_option (tentative))
    ],
    [
        # ROW0 (Layer1)
        KeyAssignment(CodeType.KEYBOARD, Keycode.ESCAPE),
        None,
        KeyAssignment(CodeType.KEYBOARD, Keycode.F1),  # ONE
        KeyAssignment(CodeType.KEYBOARD, Keycode.F2),  # TWO
        KeyAssignment(CodeType.KEYBOARD, Keycode.F3),  # THREE
        KeyAssignment(CodeType.KEYBOARD, Keycode.F4),  # FOUR
        KeyAssignment(CodeType.KEYBOARD, Keycode.F5),  # FIVE
        KeyAssignment(CodeType.KEYBOARD, Keycode.F6),  # SIX
        # ROW1 (Layer1)
        KeyAssignment(CodeType.KEYBOARD, Keycode.TAB),
        None,
        None,
        KeyAssignment(CodeType.KEYBOARD, Keycode.HOME),  # Q
        KeyAssignment(CodeType.KEYBOARD, Keycode.UP_ARROW),  # W
        KeyAssignment(CodeType.KEYBOARD, Keycode.END),  # E
        KeyAssignment(CodeType.KEYBOARD, Keycode.PAGE_UP),  # R
        KeyAssignment(CodeType.KEYBOARD, Keycode.T),
        # ROW2 (Layer1)
        None,  # MO(1)
        KeyAssignment(CodeType.KEYBOARD, Keycode.Z),
        KeyAssignment(CodeType.KEYBOARD, Keycode.X),
        KeyAssignment(CodeType.KEYBOARD, Keycode.LEFT_ARROW),  # A
        KeyAssignment(CodeType.KEYBOARD, Keycode.DOWN_ARROW),  # S
        KeyAssignment(CodeType.KEYBOARD, Keycode.RIGHT_ARROW),  # D
        KeyAssignment(CodeType.KEYBOARD, Keycode.PAGE_DOWN),  # F
        KeyAssignment(CodeType.KEYBOARD, Keycode.G),
        # ROW3 (Layer1)
        KeyAssignment(CodeType.KEYBOARD, Keycode.LEFT_SHIFT),
        KeyAssignment(CodeType.KEYBOARD, Keycode.LEFT_CONTROL),
        KeyAssignment(CodeType.KEYBOARD, Keycode.LEFT_ALT),  # left_option
        ComplexModifierAssignment(Keycode.LEFT_GUI, KeycodeJp.JAPANESE_EISUU),  # left_command
        KeyAssignment(CodeType.KEYBOARD, Keycode.SPACE),
        KeyAssignment(CodeType.KEYBOARD, Keycode.C),
        KeyAssignment(CodeType.KEYBOARD, Keycode.V),
        KeyAssignment(CodeType.KEYBOARD, Keycode.B),
        # ROW4 (Layer1)
        KeyAssignment(CodeType.KEYBOARD, Keycode.F7),  # SEVEN
        KeyAssignment(CodeType.KEYBOARD, Keycode.F8),  # EIGHT
        KeyAssignment(CodeType.KEYBOARD, Keycode.F9),  # NINE
        KeyAssignment(CodeType.KEYBOARD, Keycode.F10),  # ZERO
        KeyAssignment(CodeType.KEYBOARD, Keycode.F11),  # MINUS
        KeyAssignment(CodeType.KEYBOARD, Keycode.F12),  # EQUALS
        KeyAssignment(CodeType.KEYBOARD, Keycode.BACKSLASH),
        KeyAssignment(CodeType.KEYBOARD, Keycode.GRAVE_ACCENT),
        # ROW5 (Layer1)
        KeyAssignment(CodeType.KEYBOARD, Keycode.Y),
        KeyAssignment(CodeType.KEYBOARD, Keycode.BACKSPACE),  # U
        KeyAssignment(CodeType.KEYBOARD, Keycode.I),
        KeyAssignment(CodeType.KEYBOARD, Keycode.O),
        KeyAssignment(CodeType.KEYBOARD, Keycode.P),
        KeyAssignment(CodeType.KEYBOARD, Keycode.LEFT_BRACKET),
        KeyAssignment(CodeType.KEYBOARD, Keycode.RIGHT_BRACKET),
        KeyAssignment(CodeType.KEYBOARD, Keycode.BACKSPACE),
        # ROW6 (Layer1)
        KeyAssignment(CodeType.KEYBOARD, Keycode.ENTER),  # H
        KeyAssignment(CodeType.KEYBOARD, KeycodeJp.JAPANESE_KANA),  # J
        KeyAssignment(CodeType.KEYBOARD, Keycode.K),
        KeyAssignment(CodeType.KEYBOARD, Keycode.L),
        KeyAssignment(CodeType.KEYBOARD, Keycode.SEMICOLON),
        KeyAssignment(CodeType.KEYBOARD, Keycode.QUOTE),
        KeyAssignment(CodeType.KEYBOARD, Keycode.RETURN),
        None,  # MO(2)
        # ROW7 (Layer1)
        KeyAssignment(CodeType.KEYBOARD, Keycode.N),
        KeyAssignment(CodeType.KEYBOARD, Keycode.M),
        KeyAssignment(CodeType.KEYBOARD, Keycode.COMMA),
        KeyAssignment(CodeType.KEYBOARD, Keycode.PERIOD),
        KeyAssignment(CodeType.KEYBOARD, Keycode.FORWARD_SLASH),
        KeyAssignment(CodeType.KEYBOARD, Keycode.RIGHT_SHIFT),
        ComplexModifierAssignment(Keycode.RIGHT_GUI, KeycodeJp.JAPANESE_KANA),  # right_command
        KeyAssignment(CodeType.KEYBOARD, Keycode.RIGHT_ALT),  # right_option (tentative))
    ],
    [
        # ROW0 (Layer2)
        KeyAssignment(CodeType.KEYBOARD, Keycode.ESCAPE),
        None,
        KeyAssignment(CodeType.KEYBOARD, Keycode.F1),  # ONE
        KeyAssignment(CodeType.KEYBOARD, Keycode.F2),  # TWO
        KeyAssignment(CodeType.KEYBOARD, Keycode.F3),  # THREE
        KeyAssignment(CodeType.KEYBOARD, Keycode.F4),  # FOUR
        KeyAssignment(CodeType.KEYBOARD, Keycode.F5),  # FIVE
        KeyAssignment(CodeType.KEYBOARD, Keycode.F6),  # SIX
        # ROW1 (Layer2)
        KeyAssignment(CodeType.KEYBOARD, Keycode.TAB),
        None,
        None,
        KeyAssignment(CodeType.KEYBOARD, Keycode.Q),
        KeyAssignment(CodeType.KEYBOARD, Keycode.W),
        KeyAssignment(CodeType.KEYBOARD, Keycode.E),
        KeyAssignment(CodeType.KEYBOARD, Keycode.R),
        KeyAssignment(CodeType.KEYBOARD, Keycode.T),
        # ROW2 (Layer2)
        KeyAssignment(CodeType.KEYBOARD, Keycode.CAPS_LOCK),  # MO(1)
        KeyAssignment(CodeType.KEYBOARD, Keycode.Z),
        KeyAssignment(CodeType.KEYBOARD, Keycode.X),
        KeyAssignment(CodeType.KEYBOARD, Keycode.A),
        KeyAssignment(CodeType.KEYBOARD, Keycode.S),
        KeyAssignment(CodeType.KEYBOARD, Keycode.D),
        KeyAssignment(CodeType.KEYBOARD, Keycode.F),
        KeyAssignment(CodeType.KEYBOARD, Keycode.G),
        # ROW3 (Layer2)
        KeyAssignment(CodeType.KEYBOARD, Keycode.LEFT_SHIFT),
        KeyAssignment(CodeType.KEYBOARD, Keycode.LEFT_CONTROL),
        KeyAssignment(CodeType.KEYBOARD, Keycode.LEFT_ALT),  # left_option
        ComplexModifierAssignment(Keycode.LEFT_GUI, KeycodeJp.JAPANESE_EISUU),  # left_command
        KeyAssignment(CodeType.KEYBOARD, Keycode.SPACE),
        KeyAssignment(CodeType.KEYBOARD, Keycode.C),
        KeyAssignment(CodeType.KEYBOARD, Keycode.V),
        KeyAssignment(CodeType.KEYBOARD, Keycode.B),
        # ROW4 (Layer2)
        KeyAssignment(CodeType.KEYBOARD, Keycode.F7),  # SEVEN
        KeyAssignment(CodeType.KEYBOARD, Keycode.F8),  # EIGHT
        KeyAssignment(CodeType.KEYBOARD, Keycode.F9),  # NINE
        KeyAssignment(CodeType.KEYBOARD, Keycode.F10),  # ZERO
        KeyAssignment(CodeType.KEYBOARD, Keycode.F11),  # MINUS
        KeyAssignment(CodeType.KEYBOARD, Keycode.F12),  # EQUALS
        KeyAssignment(CodeType.KEYBOARD, Keycode.BACKSLASH),
        KeyAssignment(CodeType.KEYBOARD, Keycode.GRAVE_ACCENT),
        # ROW5 (Layer2)
        KeyAssignment(CodeType.KEYBOARD, Keycode.Y),
        KeyAssignment(CodeType.KEYBOARD, Keycode.U),
        KeyAssignment(CodeType.KEYBOARD, Keycode.I),
        KeyAssignment(CodeType.KEYBOARD, Keycode.O),
        KeyAssignment(CodeType.KEYBOARD, Keycode.P),
        KeyAssignment(CodeType.KEYBOARD, Keycode.UP_ARROW),  # LEFT_BRACKET
        KeyAssignment(CodeType.KEYBOARD, Keycode.RIGHT_BRACKET),
        KeyAssignment(CodeType.KEYBOARD, Keycode.BACKSPACE),
        # ROW6 (Layer2)
        KeyAssignment(CodeType.KEYBOARD, Keycode.H),
        KeyAssignment(CodeType.KEYBOARD, Keycode.J),
        KeyAssignment(CodeType.KEYBOARD, Keycode.K),
        KeyAssignment(CodeType.KEYBOARD, Keycode.L),
        KeyAssignment(CodeType.KEYBOARD, Keycode.LEFT_ARROW),  # SEMICOLON
        KeyAssignment(CodeType.KEYBOARD, Keycode.RIGHT_ARROW),  # QUOTE
        KeyAssignment(CodeType.KEYBOARD, Keycode.RETURN),
        None,  # MO(2)
        # ROW7 (Layer2)
        KeyAssignment(CodeType.KEYBOARD, Keycode.N),
        KeyAssignment(CodeType.KEYBOARD, Keycode.M),
        KeyAssignment(CodeType.KEYBOARD, Keycode.COMMA),
        KeyAssignment(CodeType.KEYBOARD, Keycode.PERIOD),
        KeyAssignment(CodeType.KEYBOARD, Keycode.DOWN_ARROW),  # FORWARD_SLASH
        KeyAssignment(CodeType.KEYBOARD, Keycode.RIGHT_SHIFT),
        ComplexModifierAssignment(Keycode.RIGHT_GUI, KeycodeJp.JAPANESE_KANA),  # right_command
        KeyAssignment(CodeType.KEYBOARD, Keycode.RIGHT_ALT),  # right_option (tentative))
    ],
]


class ComplexModifierStatus:
  def __init__(self):
    self.is_still_standalone = True


if __name__ == '__main__':
  key_matrix = KeyMatrix()
  key_event_planners = [KeyEventPlanner() for _ in range(len(key_matrix.row_ios) * len(key_matrix.col_ios))]

  cpu_pixpower = digitalio.DigitalInOut(board.NEOPIX_POWER)
  cpu_pixpower.switch_to_output(True, digitalio.DriveMode.PUSH_PULL)

  # Sleep for a bit to avoid a race condition on some systems
  time.sleep(2)

  while True:
    try:
      keyboard = Keyboard(usb_hid.devices)
      keyboard_layout = KeyboardLayoutUS(keyboard)
      mouse = Mouse(usb_hid.devices)
      consumer_control = ConsumerControl(usb_hid.devices)

      key_events = [None for _ in range(len(key_event_planners))]
      key_map_layer = 0
      pressed_keys = [None for _ in range(len(key_event_planners))]
      complex_modifier_status_list = [None for _ in range(len(key_event_planners))]

      scan_key_matrix_timing = time.monotonic()  # For debounce
      while True:
        current_time = time.monotonic()

        if current_time >= scan_key_matrix_timing:
          are_keys_pressed = key_matrix.scan_matrix()
          for i, key_event_planner in enumerate(key_event_planners):
            key_events[i] = key_event_planner.make_event(
                current_time, are_keys_pressed[i])

          # Check whether to stop standalone of complex modifiers
          stop_standalone_of_complex_modifiers = False
          for i, key_event in enumerate(key_events):
            if key_event == KeyEvent.PRESS:
              if isinstance(KEY_MAP_LAYERS[key_map_layer][i], KeyAssignment):
                stop_standalone_of_complex_modifiers = True
          if stop_standalone_of_complex_modifiers:
            for i in range(len(complex_modifier_status_list)):
              if complex_modifier_status_list[i] is not None and complex_modifier_status_list[i].is_still_standalone:
                complex_modifier_status_list[i].is_still_standalone = False
                if (pressed_keys[i].modifier == KeycodeLayer.MO1):
                  key_map_layer = 1
                elif (pressed_keys[i].modifier == KeycodeLayer.MO2):
                  key_map_layer = 2
                else:
                  keyboard.press(pressed_keys[i].modifier)

          for i, key_event in enumerate(key_events):
            if key_event == KeyEvent.PRESS:
              # print(f"""pressed : {i}""")
              pressed_keys[i] = KEY_MAP_LAYERS[key_map_layer][i]
              key_assignment = pressed_keys[i]
              if key_assignment is None:
                pass
              elif isinstance(key_assignment, ComplexModifierAssignment):
                complex_modifier_status_list[i] = ComplexModifierStatus()
              elif isinstance(key_assignment, KeyAssignment):
                if key_assignment.type == CodeType.KEYBOARD:
                  if (key_assignment.code == KeycodeLayer.MO1):
                    key_map_layer = 1
                  elif (key_assignment.code == KeycodeLayer.MO2):
                    key_map_layer = 2
                  else:
                    keyboard.press(key_assignment.code)
                elif key_assignment.type == CodeType.MOUSE_MOVE:
                  mouse.move(**key_assignment.code)
                elif key_assignment.type == CodeType.MOUSE_BUTTON:
                  mouse.press(key_assignment.code)
                elif key_assignment.type == CodeType.CONSUMER_CONTROL:
                  consumer_control.press(key_assignment.code)
              elif isinstance(key_assignment, LambdaAssignment) and key_assignment.on_press is not None:
                key_assignment.on_press()
            elif key_event == KeyEvent.LONG_PRESS:
              # print(f"""pressed : {i}""")
              key_assignment = pressed_keys[i]
              if key_assignment is None:
                pass
              elif isinstance(key_assignment, ComplexModifierAssignment):
                if complex_modifier_status_list[i].is_still_standalone:
                  complex_modifier_status_list[i].is_still_standalone = False
                  if (key_assignment.modifier == KeycodeLayer.MO1):
                    key_map_layer = 1
                  elif (key_assignment.modifier == KeycodeLayer.MO2):
                    key_map_layer = 2
                  else:
                    keyboard.press(key_assignment.modifier)
              elif isinstance(key_assignment, KeyAssignment):
                if key_assignment.type == CodeType.KEYBOARD:
                  # print(f"""pressed : {i}""")
                  if not is_code_mo(key_assignment.code):
                    keyboard.press(key_assignment.code)
                elif key_assignment.type == CodeType.MOUSE_MOVE:
                  # print(f"""pressed : {i}""")
                  mouse.move(**key_assignment.code)
            elif key_event == KeyEvent.RELEASE:
              # print(f"""released: {i}""")
              key_assignment = pressed_keys[i]
              pressed_keys[i] = None
              if key_assignment is None:
                pass
              elif isinstance(key_assignment, ComplexModifierAssignment):
                complex_modifier_status = complex_modifier_status_list[i]
                if complex_modifier_status.is_still_standalone:
                  if not is_code_mo(key_assignment.code_for_standalone):
                    keyboard.press(key_assignment.code_for_standalone)
                    keyboard.release(key_assignment.code_for_standalone)
                else:
                  if is_code_mo(key_assignment.modifier):
                    key_map_layer = 0
                  else:
                    keyboard.release(key_assignment.modifier)
                complex_modifier_status_list[i] = None
              elif isinstance(key_assignment, KeyAssignment):
                if key_assignment.type == CodeType.KEYBOARD:
                  if is_code_mo(key_assignment.code):
                    key_map_layer = 0
                  else:
                    keyboard.release(key_assignment.code)
                elif key_assignment.type == CodeType.MOUSE_BUTTON:
                  mouse.release(key_assignment.code)
                elif key_assignment.type == CodeType.CONSUMER_CONTROL:
                  consumer_control.release()
              elif isinstance(key_assignment, LambdaAssignment) and key_assignment.on_release is not None:
                key_assignment.on_release()

          scan_key_matrix_timing += SCAN_KEY_MATRIX_INTERVAL
          if scan_key_matrix_timing <= current_time:
            scan_key_matrix_timing = current_time + SCAN_KEY_MATRIX_INTERVAL

    except Exception:
      time.sleep(3)

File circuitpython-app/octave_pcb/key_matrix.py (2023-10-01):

import time

import board
import digitalio

DIGITALIO_HIGH = True
DIGITALIO_LOW = False


class KeyMatrix:
  def __init__(self):
    row_pins = [board.GPIO29, board.GPIO28, board.GPIO27, board.GPIO26,
                board.GPIO25, board.GPIO24, board.GPIO23, board.GPIO22]
    self.row_ios = [digitalio.DigitalInOut(pin) for pin in row_pins]
    for row_io in self.row_ios:
      row_io.switch_to_output(DIGITALIO_HIGH, digitalio.DriveMode.OPEN_DRAIN)

    col_pins = [board.GPIO21, board.GPIO20, board.GPIO19, board.GPIO18,
                board.GPIO17, board.GPIO16, board.GPIO15, board.GPIO14]
    self.col_ios = [digitalio.DigitalInOut(pin) for pin in col_pins]
    for col_io in self.col_ios:
      col_io.switch_to_input(digitalio.Pull.UP)

  def deinit(self):
    self.select_row(-1)
    for row_io in self.row_ios:
      row_io.deinit()
    for col_io in self.col_ios:
      col_io.deinit()

  def select_row(self, row):
    # Once deselect all rows
    for row_io in self.row_ios:
      row_io.value = DIGITALIO_HIGH
    if 0 <= row <= len(self.row_ios):
      self.row_ios[row].value = DIGITALIO_LOW

  def scan_matrix(self):
    are_keys_pressed = []
    for row in range(len(self.row_ios)):
      self.select_row(row)
      are_keys_pressed.extend(
          [True if col_io.value == DIGITALIO_LOW else False for col_io in self.col_ios]
      )
      # time.sleep(0.001)
    return are_keys_pressed

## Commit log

2023-07-08 Add KiCad project and project library
    [Five_Octave_Keys.kicad_pcb, Five_Octave_Keys.kicad_sch]
2023-07-08 Fix library path
    [Five_Octave_Keys.kicad_pcb]
2023-07-08 Add 8x8 key matrix schematic
    [Five_Octave_Keys.kicad_pcb, Five_Octave_Keys.kicad_sch]
2023-07-09 Modify footprint of hot-swap socket
2023-07-09 Add footprint of stabilizer (2u)
2023-07-15 Adjust footprint of stabilizer (2u)
2023-07-15 Add footprint of stabilizer (6.25u)
2023-07-27 Adjust stabilizer holes
2023-07-29 Assign C2128 to the LCSC value of 1N4148WS
    [Five_Octave_Keys.kicad_sch]
2023-07-29 Add connector footprint
2023-07-29 Add FFC connector
    [Five_Octave_Keys.kicad_sch]
2023-07-29 Layout Keys board
    [Five_Octave_Keys.kicad_pcb]
2023-07-30 Wire diodes to switches
    [Five_Octave_Keys.kicad_pcb]
2023-07-31 Route some diodes
    [Five_Octave_Keys.kicad_pcb]
2023-08-01 Adjust key-matrix
    [Five_Octave_Keys.kicad_pcb, Five_Octave_Keys.kicad_sch]
2023-08-05 Update pcb
    [Five_Octave_Keys.kicad_pcb]
2023-08-09 Adjust footprint of FCC connector
    [Five_Octave_Keys.kicad_pcb]
2023-08-09 Add 3d shape for FCC connector
    [Five_Octave_Keys.kicad_pcb]
2023-08-10 Update
    - Assign JLCPCB part number to SW1-61
    - GH60 compatible
    [Five_Octave_Keys.kicad_pcb, Five_Octave_Keys.kicad_sch]
2023-08-10 Decorate PCB with silkscreen
    [Five_Octave_Keys.kicad_pcb]
2023-08-12 Fix footprint orientation for PCBA
    [Five_Octave_Keys.kicad_pcb]
2023-08-12 Remove screw holes
    [Five_Octave_Keys.kicad_pcb]
2023-08-12 Start MCU board design
    [Five_Octave_MCU.kicad_pcb, Five_Octave_MCU.kicad_sch]
2023-08-14 Assign LCSC values
    [Five_Octave_MCU.kicad_pcb, Five_Octave_MCU.kicad_sch]
2023-08-14 Round off insignificant decimals
    [Five_Octave_MCU.kicad_pcb]
2023-08-14 Update footprint
    [Five_Octave_MCU.kicad_pcb]
2023-08-14 Change zone pad connections to thermal reliefs
    [Five_Octave_MCU.kicad_pcb]
2023-08-14 Update footprint for FFC connector
    [Five_Octave_Keys.kicad_pcb, Five_Octave_Keys.kicad_sch]
2023-08-14 Change M2 footprint
    [Five_Octave_Keys.kicad_pcb]
2023-08-15 Fix FFC connector assignment
    [Five_Octave_MCU.kicad_pcb, Five_Octave_MCU.kicad_sch]
2023-08-15 Add plate design
    [Five_Octave_Plate.kicad_pcb]
2023-08-15 Improve edge-cuts layer
    [Five_Octave_Plate.kicad_pcb]
2023-08-15 Fix Shift and Fn key size
    [Five_Octave_Keys.kicad_pcb]
2023-08-15 Modify outline curve
    [Five_Octave_Keys.kicad_pcb, Five_Octave_Plate.kicad_pcb]
2023-08-20 Add enclosure design (WIP)
    [Five_Octave_Enclosure.FCStd]
2023-08-21 Change footprint for AP2112K-3.3
    [Five_Octave_Keys.kicad_pcb, Five_Octave_MCU.kicad_pcb, Five_Octave_MCU.kicad_sch]
2023-08-21 Update build number
    [Five_Octave_Keys.kicad_pcb, Five_Octave_MCU.kicad_pcb]
2023-08-21 Update version
    [Five_Octave_Plate.kicad_pcb]
2023-08-22 Add PCBA ver of Keys PCB
    [Five_Octave_Keys-PCBA.kicad_pcb]
2023-08-24 Improve enclosure
    [Five_Octave_Enclosure.FCStd]
2023-08-26 Update enclosure
    Add weight-bar
    [Five_Octave_Enclosure.FCStd]
2023-08-28 Add decorative dimple to an enclosure
    [Five_Octave_Enclosure.FCStd]
2023-08-29 Update enclosure
    [Five_Octave_Enclosure.FCStd]
2023-08-30 Fix FFC cable type
2023-09-11 Update inner R of enclosure for CNC
    [Five_Octave_Enclosure.FCStd]
2023-09-28 Add Esc key press event
2023-09-28 Change to boot without mounting
2023-10-01 Add TechDraw of Case
    [Five_Octave_Enclosure.FCStd]
2023-10-22 Fix top frame inner radius, expand the space with the key switch
    [Five_Octave_Enclosure.FCStd]
2023-10-22 Add BOM of enclosure
2023-10-31 Modify top frame design
    - Extend the margin with the keys.
    - Make the height thinner.
    - Fine-tune the bottom-right dimple.
    [Five_Octave_Enclosure.FCStd]
2023-11-11 Add TechDraw
    [Five_Octave_Enclosure_v2.FCStd]
2023-11-11 Add foot guide
    [Five_Octave_Enclosure_v2.FCStd]
2023-11-18 Update enclosure design
    [Five_Octave_Enclosure_v2.FCStd]
2023-11-19 V up enclosure v2
2023-11-21 Remove burr
    [Five_Octave_Enclosure_v2.FCStd]
2023-12-09 Fix MCU screw hole depth of case-v2
    [Five_Octave_Enclosure_v2.FCStd]

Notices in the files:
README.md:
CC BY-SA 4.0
